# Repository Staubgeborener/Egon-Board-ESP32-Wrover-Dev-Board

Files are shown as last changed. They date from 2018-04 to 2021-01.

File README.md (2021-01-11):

These are parts (created with eagle) for a ESP32 Dev Board. You also find the bom file inside.
The board has support for a sd card adapter and also for LiPo. Keep in mind, that this pcb is for the ESP32 **Wrover** NOT for the wroom (different pinout)!

All necessary parts are in this repo. So you can just download this and create the pcb at your manufactory of trust.

<p align="center">
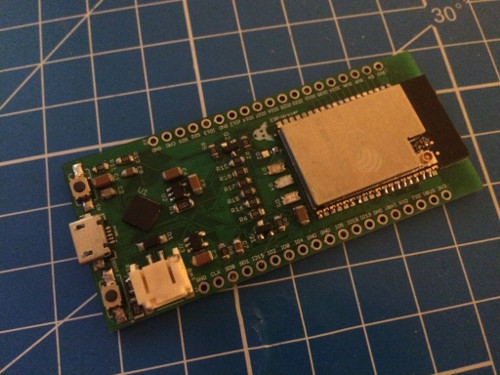
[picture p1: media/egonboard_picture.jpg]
  
</p>

But just take a closer look:
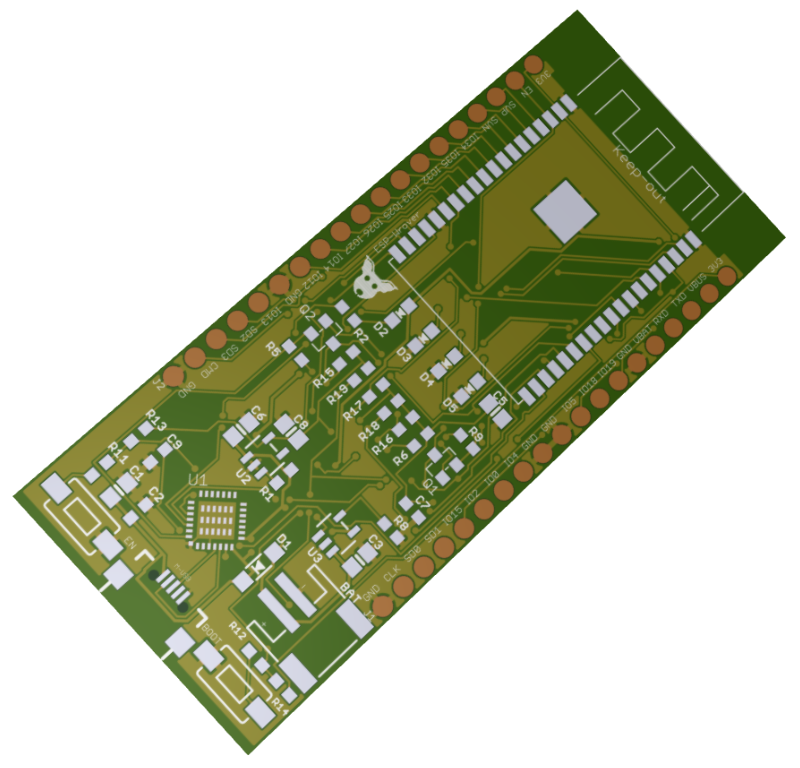
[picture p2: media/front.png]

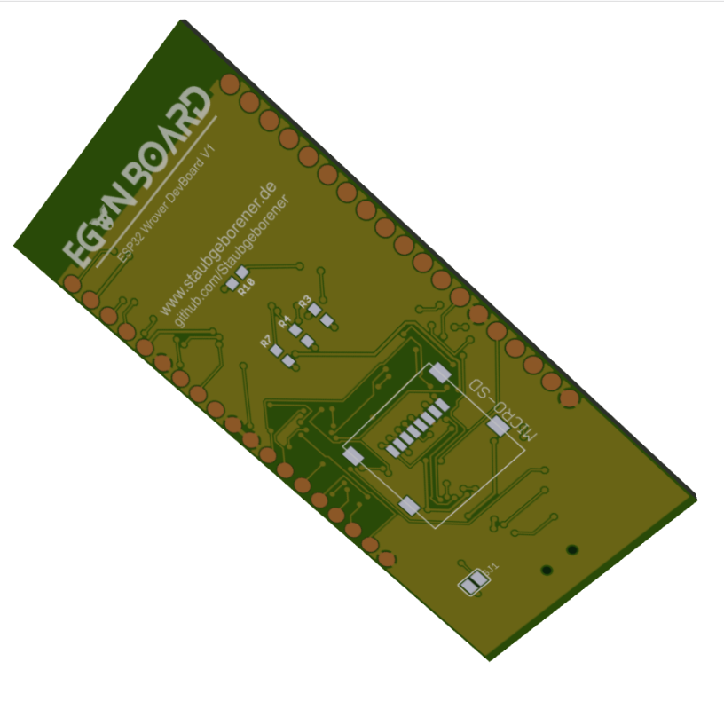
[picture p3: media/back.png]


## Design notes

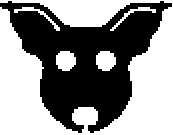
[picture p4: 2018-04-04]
media/egonboard_head.png

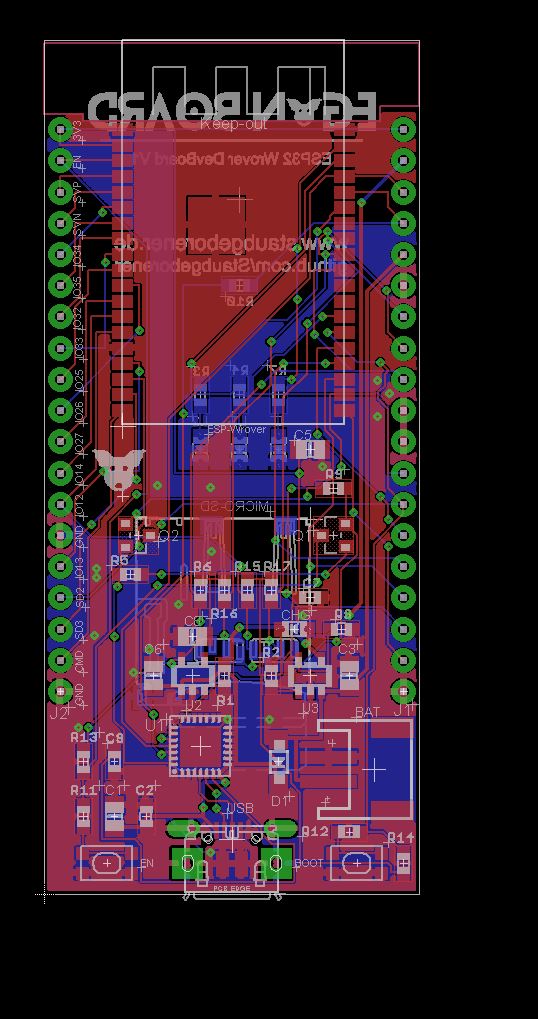
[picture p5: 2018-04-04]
media/layout-2.JPG

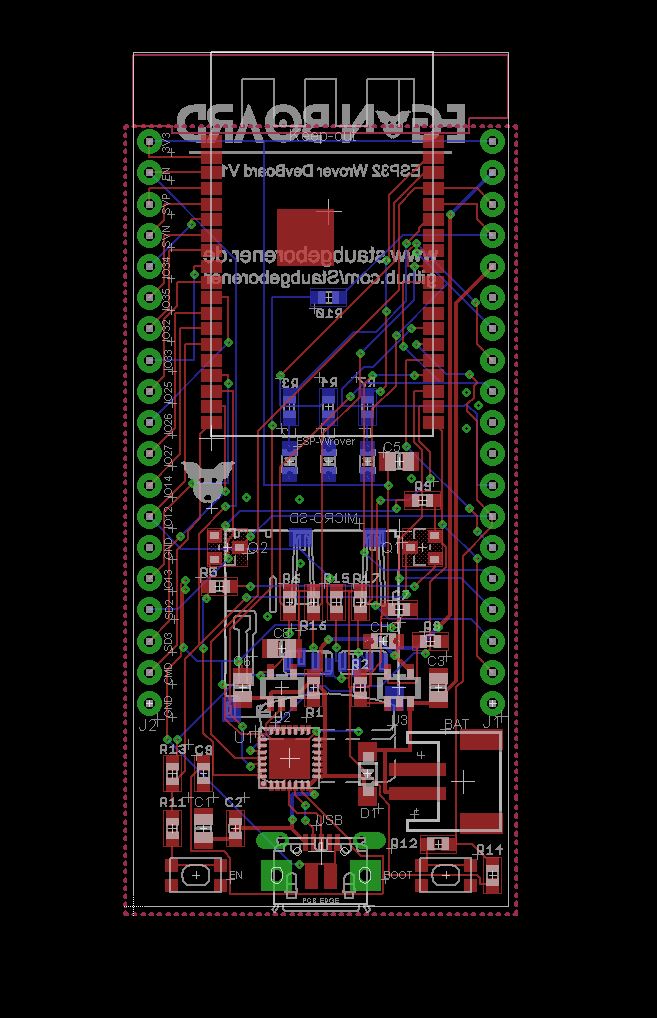
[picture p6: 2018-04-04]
media/layout-1.JPG

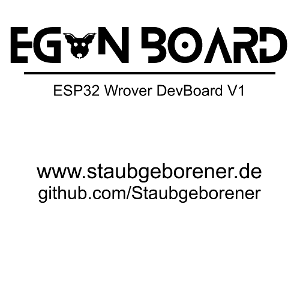
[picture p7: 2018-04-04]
media/logo.png

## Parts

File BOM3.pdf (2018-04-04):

Part | Value | Web link
BAT | JSTPH | N.A
C1 | 10µF | N.A
C2 | 100nf | https://www.conrad.de/de/keramik-kondensator-smd-0603-100-nf-50-v-10-samsung-electro-mechanics-cl10b104kb8nnnc-4000-st-456651.html
C3 | 10µF | N.A
C5 | 10uF | N.A
C6 | 10µF | N.A
C7 | 1uF | N.A
C8 | 10µF | N.A
C9 | 1uF | N.A
D1 | MBR120 | N.A
D2 | ORANGE | https://www.conrad.de/de/smd-led-0805-orange-8-mcd-170-20-ma-22-v-broadcom-hsmd-c170-180497.html
D3 | YELLOW | https://www.conrad.de/de/smd-led-0805-gelb-43-mcd-140-20-ma-2-v-everlight-opto-17-21uycs530-a2tr8-156305.html
D4 | GREEN | N.A
D5 | RED | https://www.conrad.de/de/smd-led-0805-rot-38-mcd-140-20-ma-2-v-everlight-opto-17-21surcs530-a2tr8-156300.html
J1 | | N.A
J2 | | N.A
J3 | | https://www.conrad.de/de/wr-crd-micro-sd-kartensockel-mit-deckel-8-pins-pole-8-wuerth-elektronik-inhalt-1-st-1088844.html
Q1 | S8050 | N.A
Q2 | S8050 | N.A
R1 | 100k | https://www.conrad.de/de/dickschicht-widerstand-100-k-smd-0603-01-w-1-200-ppmc-royalohm-0603saf1003t5e-1-st-1208573.html
R2 | 1K | N.A
R3 | 1K | N.A
R4 | 1K | N.A
R5 | 12k | N.A
R6 | 10k | https://www.conrad.de/de/dickschicht-widerstand-10-k-smd-0603-01-w-1-400-ppmc-royalohm-0603saf1002t5e-1-st-1208549.html
R7 | 2.2K | N.A
R8 | 10K\ | https://www.conrad.de/de/dickschicht-widerstand-10-k-smd-0603-01-w-1-400-ppmc-royalohm-0603saf1002t5e-1-st-1208549.html
R9 | 12k | N.A
R10 | 470R | https://www.conrad.de/de/metallschicht-widerstand-470-smd-0603-01-w-1-50-ppm-weltron-ar03ftdx4700-1-st-445683.html
R11 | 470R | https://www.conrad.de/de/metallschicht-widerstand-470-smd-0603-01-w-1-50-ppm-weltron-ar03ftdx4700-1-st-445683.html
R12 | 470R | https://www.conrad.de/de/metallschicht-widerstand-470-smd-0603-01-w-1-50-ppm-weltron-ar03ftdx4700-1-st-445683.html
R13 | 12k | N.A
R14 | 12k | N.A
R15 | 10k | https://www.conrad.de/de/dickschicht-widerstand-10-k-smd-0603-01-w-1-400-ppmc-royalohm-0603saf1002t5e-1-st-1208549.html
R16 | 10k | https://www.conrad.de/de/dickschicht-widerstand-10-k-smd-0603-01-w-1-400-ppmc-royalohm-0603saf1002t5e-1-st-1208549.html
R17 | 10k | https://www.conrad.de/de/dickschicht-widerstand-10-k-smd-0603-01-w-1-400-ppmc-royalohm-0603saf1002t5e-1-st-1208549.html
R18 | 10k | https://www.conrad.de/de/dickschicht-widerstand-10-k-smd-0603-01-w-1-400-ppmc-royalohm-0603saf1002t5e-1-st-1208549.html
R19 | 10k | https://www.conrad.de/de/dickschicht-widerstand-10-k-smd-0603-01-w-1-400-ppmc-royalohm-0603saf1002t5e-1-st-1208549.html
SJ1 | | Not a PCB component.
SW1 | SPST_TACT-KMR2 | https://www.conrad.de/de/drucktaster-12-vdc-005-a-1-x-ausein-wuerth-elektronik-ws-tsw-434111050826-tastend-1-st-711749.html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
SW2 | SPST_TACT-KMR2 | https://www.conrad.de/de/drucktaster-12-vdc-005-a-1-x-ausein-wuerth-elektronik-ws-tsw-434111050826-tastend-1-st-711749.html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
U$2 | ESP32-WROVER
U1 | CP2102 | N.A
U2 | SPX3819-3.3 | N.A
U3 | MCP73831T-2ACI/OT | https://www.conrad.de/de/pmic-batteriemanagement-microchip-technology-mcp73831t-2aciot-lademanagement-li-ion-li-pol-sot-23-5-oberflaechenmonta-651521.html

USB | microUSB | https://www.conrad.de/de/micro-usb-einbaubuchse-buchse-einbau-horizontal-207a-bba0-r-micro-usb-einbaubuchse-typ-b-attend-inhalt-1-st-1307069.html

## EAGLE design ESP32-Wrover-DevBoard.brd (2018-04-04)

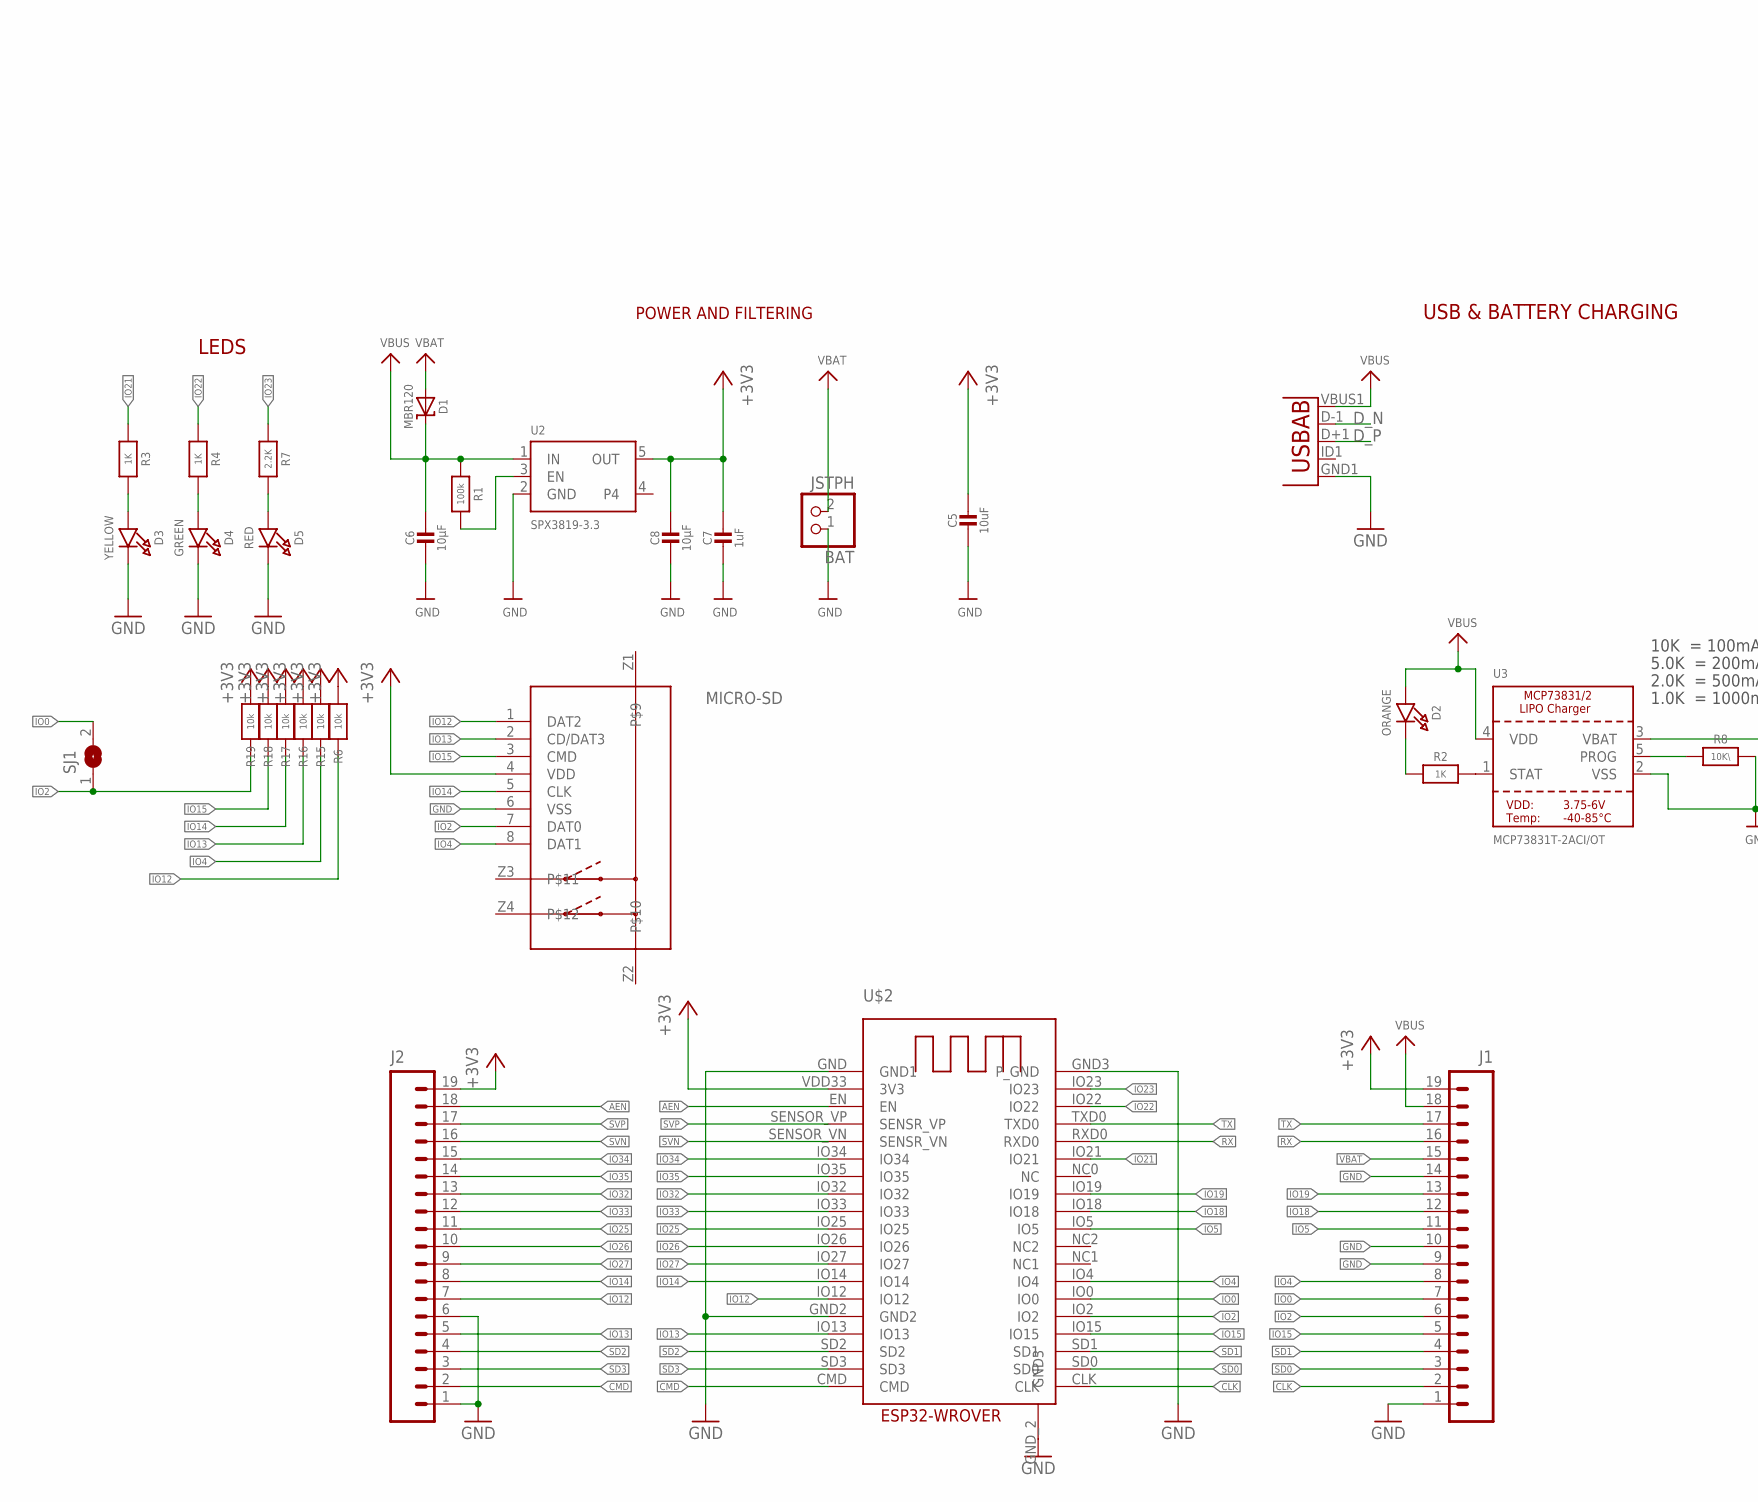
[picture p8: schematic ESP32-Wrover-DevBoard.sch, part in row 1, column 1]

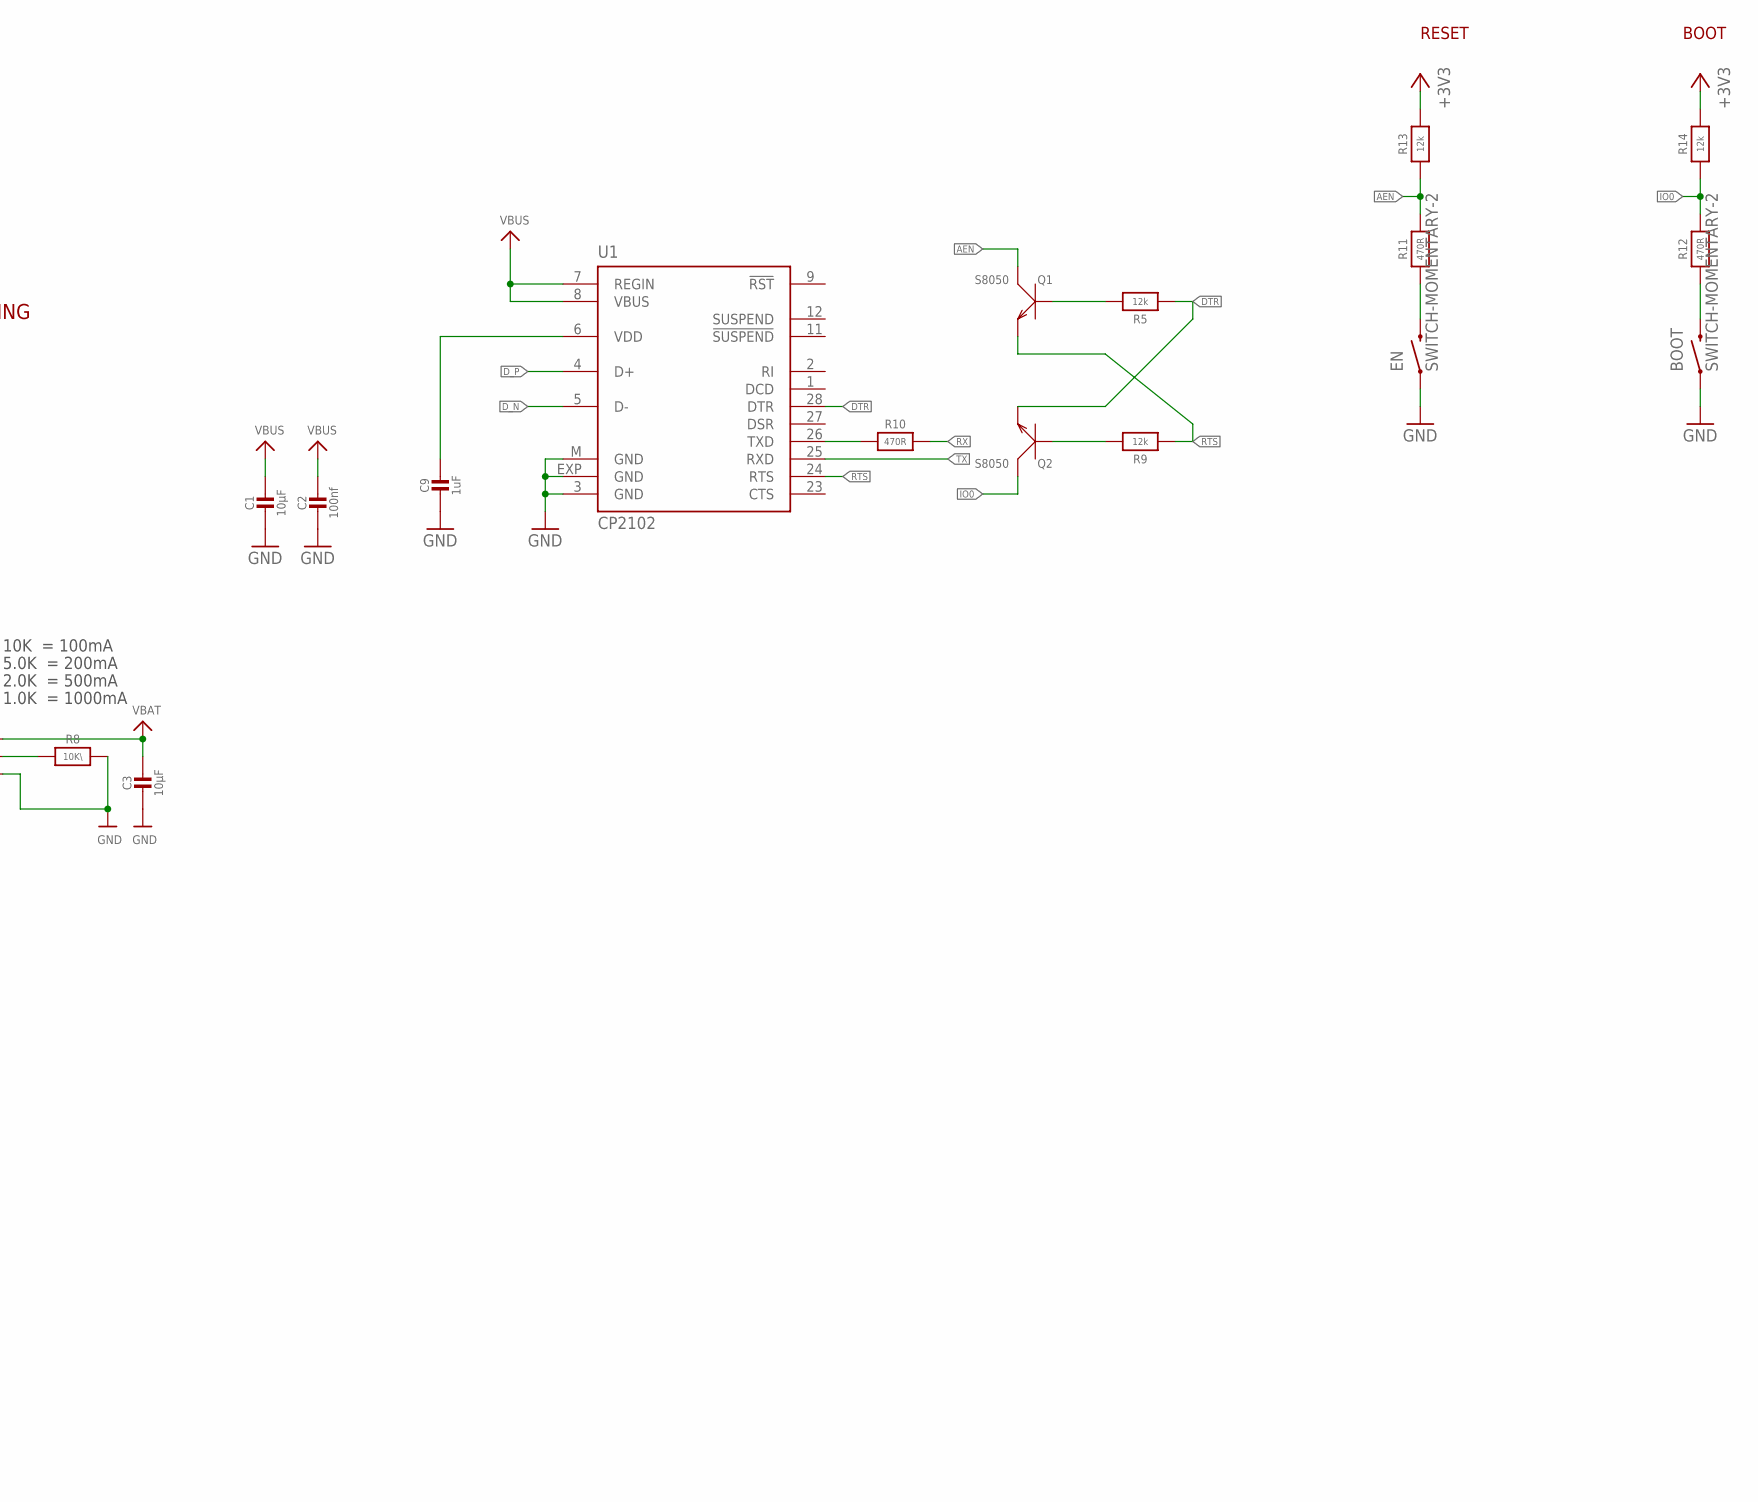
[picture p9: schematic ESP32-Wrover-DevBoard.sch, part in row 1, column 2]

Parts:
BAT: JSTPH; JSTPH2
BOOT: SWITCH-MOMENTARY-2; WS-TRS-6.0X3.5MM-TACT-SWITCH_SMD
C1, C3, C6, C8: 10µF; 0805-NO
C2: 100nf; 0603-NO
C5: 10uF; 0805-NO
C7, C9: 1uF; 0603-NO
D1: MBR120; SOD-123
D2: ORANGE; CHIPLED_0805_NOOUTLINE
D3: YELLOW; CHIPLED_0805_NOOUTLINE
D4: GREEN; CHIPLED_0805_NOOUTLINE
D5: RED; CHIPLED_0805_NOOUTLINE
EN: SWITCH-MOMENTARY-2; WS-TRS-6.0X3.5MM-TACT-SWITCH_SMD
J1, J2: M191X19_NO_SILK; 1X19_NO_SILK
M-USB: USB""; USB-MICRO-SMD
MICRO-SD: 693072010801
Q1, Q2: S8050; SOT-23
R1: 100k; 0603-NO
R2, R3, R4: 1K; 0603-NO
R5, R9, R13, R14: 12k; 0603-NO
R6, R15, R16, R17, R18, R19: 10k; 0603-NO
R7: 2.2K; 0603-NO
R8: 10K\; 0603-NO
R10, R11, R12: 470R; 0603-NO
SJ1: SJ
U1: CP2102; MLP28
U2: SPX3819-3.3; SOT23-5
U3: MCP73831T-2ACI/OT; SOT23-5
U$2: ESP32-WROVER

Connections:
+3V3: C5.1, C7.1, C8.1, J1.19, J2.19, MICRO-SD.4 (VDD), R6.1, R13.2, R14.2, R15.1, R16.1, R17.1, R18.1, R19.1, U2.5 (OUT), U$2.VDD33 (3V3)
AEN: J2.18, Q1.3 (C), R11.2, R13.1, U$2.EN
CLK: J1.2, U$2.CLK
CMD: J2.2, U$2.CMD
DTR: Q2.2 (E), R5.1, U1.28 (DTR)
D_N: M-USB.D-1 (D-), U1.5 (D-)
D_P: M-USB.D+1 (D+), U1.4 (D+)
GND: BAT.1, BOOT.1, C1.2, C2.2, C3.2, C5.2, C6.2, C7.2, C8.2, C9.2, D3.C, D4.C, D5.C, EN.1, J1.1, J1.9, J1.10, J1.14, J2.1, J2.6, M-USB.GND1 (GND), MICRO-SD.6 (VSS), R8.2, U1.3 (GND), U1.EXP (GND), U1.M (GND), U2.2 (GND), U3.2 (VSS), U$2.GND (GND1), U$2.GND2, U$2.GND3 (P_GND), U$2.GND_2 (GND3)
IO0: J1.7, Q2.3 (C), R12.2, R14.1, SJ1.2, U$2.IO0
IO2: J1.6, MICRO-SD.7 (DAT0), R19.2, SJ1.1, U$2.IO2
IO4: J1.8, MICRO-SD.8 (DAT1), R15.2, U$2.IO4
IO5: J1.11, U$2.IO5
IO12: J2.7, MICRO-SD.1 (DAT2), R6.2, U$2.IO12
IO13: J2.5, MICRO-SD.2 (CD/DAT3), R16.2, U$2.IO13
IO14: J2.8, MICRO-SD.5 (CLK), R17.2, U$2.IO14
IO15: J1.5, MICRO-SD.3 (CMD), R18.2, U$2.IO15
IO18: J1.12, U$2.IO18
IO19: J1.13, U$2.IO19
IO21: R3.1, U$2.IO21
IO22: R4.1, U$2.IO22
IO23: R7.1, U$2.IO23
IO25: J2.11, U$2.IO25
IO26: J2.10, U$2.IO26
IO27: J2.9, U$2.IO27
IO32: J2.13, U$2.IO32
IO33: J2.12, U$2.IO33
IO34: J2.15, U$2.IO34
IO35: J2.14, U$2.IO35
unnamed: D2.C, R2.1
unnamed: D5.A, R7.2
unnamed: R2.2, U3.1 (STAT)
unnamed: R8.1, U3.5 (PROG)
unnamed: R10.1, U1.26 (TXD)
unnamed: D4.A, R4.2
unnamed: Q1.1 (B), R5.2
unnamed: Q2.1 (B), R9.2
unnamed: C9.1, U1.6 (VDD)
unnamed: EN.2, R11.1
unnamed: BOOT.2, R12.1
unnamed: D3.A, R3.2
NX1: R1.2, U2.3 (EN)
RTS: Q1.2 (E), R9.1, U1.24 (RTS)
RX: J1.16, R10.2, U$2.RXD0
SD0: J1.3, U$2.SD0
SD1: J1.4, U$2.SD1
SD2: J2.4, U$2.SD2
SD3: J2.3, U$2.SD3
SVN: J2.16, U$2.SENSOR_VN (SENSR_VN)
SVP: J2.17, U$2.SENSOR_VP (SENSR_VP)
TX: J1.17, U1.25 (RXD), U$2.TXD0
VBAT: BAT.2, C3.1, D1.A, J1.15, U3.3 (VBAT)
VBUS: C1.1, C2.1, C6.1, D1.C, D2.A, J1.18, M-USB.VBUS1 (VBUS), R1.1, U1.7 (REGIN), U1.8 (VBUS), U2.1 (IN), U3.4 (VDD)

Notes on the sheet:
POWER AND FILTERING
BOOT
10K = 100mA
5.0K = 200mA
2.0K = 500mA
1.0K = 1000mA
USB & BATTERY CHARGING
LEDS
RESET

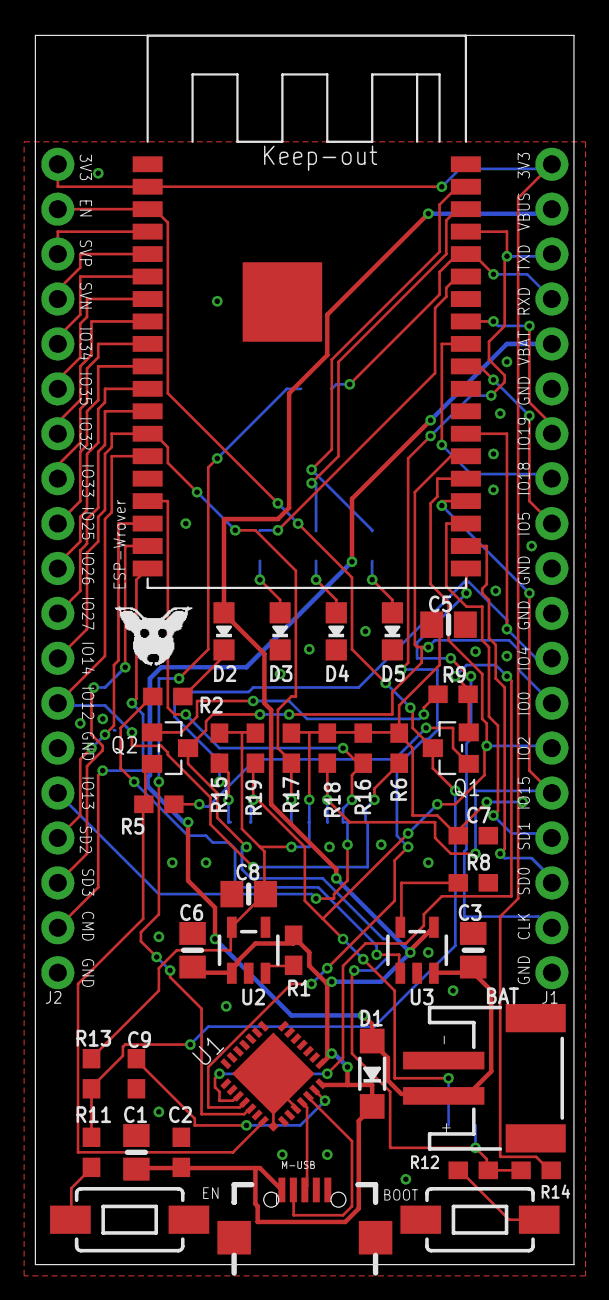
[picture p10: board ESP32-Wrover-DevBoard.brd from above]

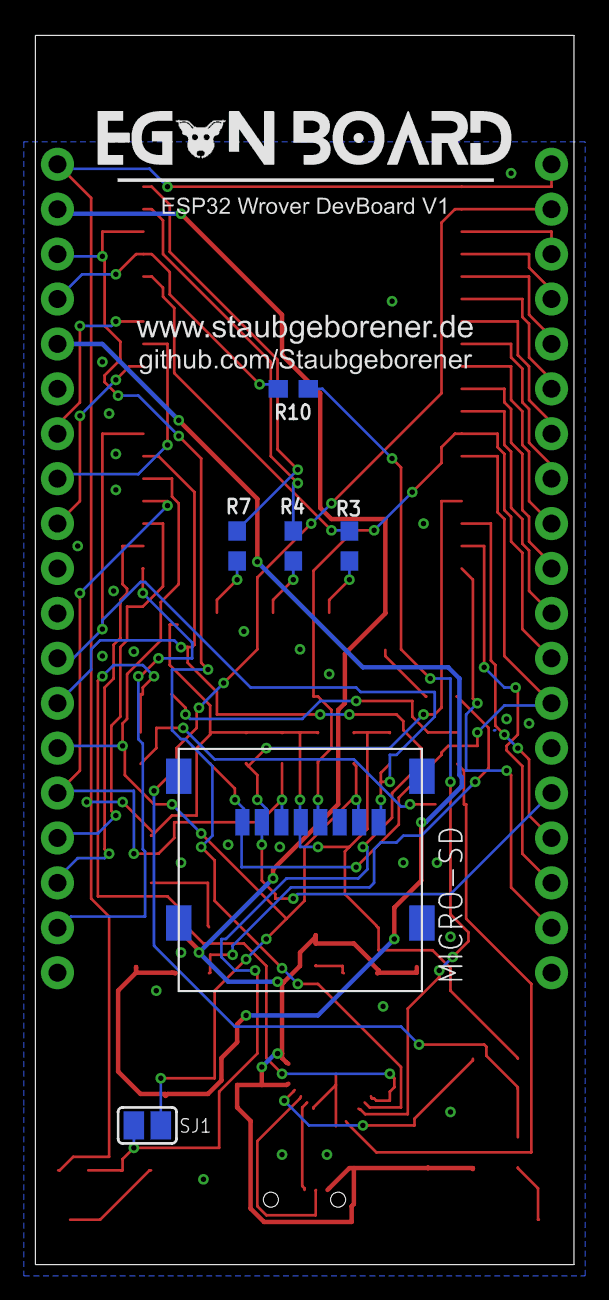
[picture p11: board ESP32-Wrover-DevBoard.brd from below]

Board: 2 copper layers, 30.5 x 69.5 mm, 48 parts (7 on the bottom side), 52 nets.

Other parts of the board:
U$8: EGON-HEAD
U$9: EGON-LOGO-SCALE-0.5

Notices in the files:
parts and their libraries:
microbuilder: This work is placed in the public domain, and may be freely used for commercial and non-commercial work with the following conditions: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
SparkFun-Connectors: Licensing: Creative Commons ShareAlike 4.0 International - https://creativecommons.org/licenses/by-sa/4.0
